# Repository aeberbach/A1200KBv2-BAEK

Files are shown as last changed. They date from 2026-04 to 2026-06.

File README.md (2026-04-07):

# A1200KBv2-BAEK</br>

What's a BAEK? It's a Big-Ass Enter Key.</br>

This is the BAEK version of the A1200KBv2 project. It is the same but for the BAEK itself and longer Left Shift key, just like the North American A2000 keyboard. These keys remove the need for two keys that are found in most A1200 keyboards, those that are blank in UK/US languages and are sometimes used for special characters in other languages.</br>
The Left Shift key is a conventionally stabilised key, same as the Right Shift. The BAEK uses the same kind of stabiliser at its base but adds another single stabiliser at the top. The key available does not provide for a vertical wire as keyboards with BAEK sometimes used - when pressing at the very top it will be slightly stiffer, but it seems to work fine.</br>
All other parts of this keyboard are substantially the same as the A1200KBv2 project.</br>

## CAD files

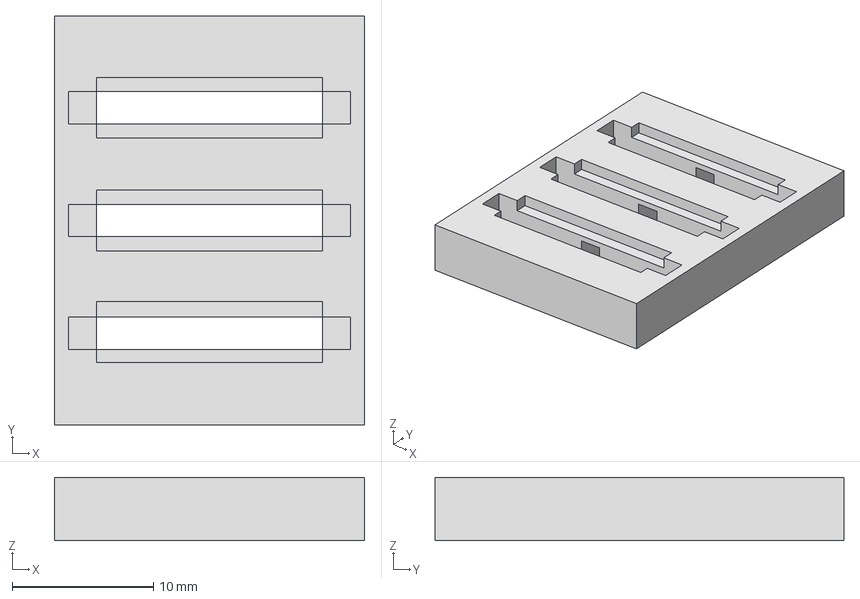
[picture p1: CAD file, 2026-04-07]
3dprint/A1200net LEDs/Lightpipe shield A1200net.stp
22.0 x 29.0 x 4.50 mm

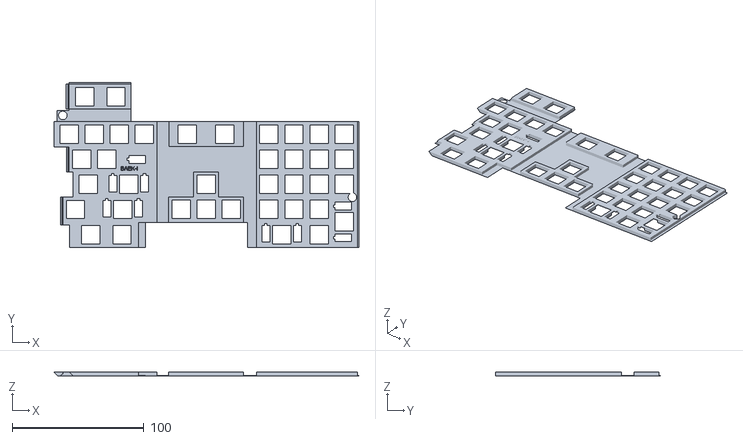
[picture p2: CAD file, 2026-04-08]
3dprint/Keyboard plates/BAEK-Right Plate.stl
231.7 x 125.0 x 3.00

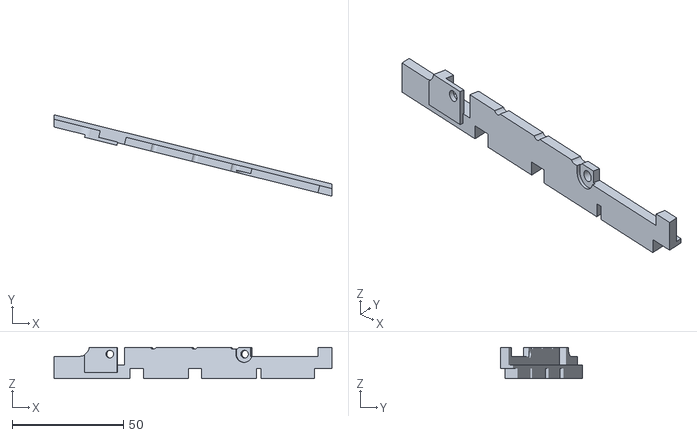
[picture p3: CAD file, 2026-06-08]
3dprint/Mounts/Universal Right Mount-Universal right mount.stl
125.2 x 36.7 x 14.0

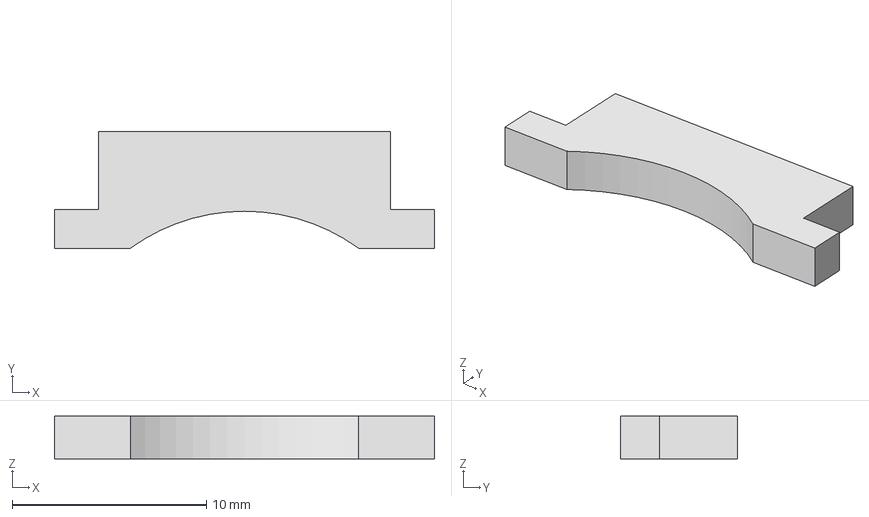
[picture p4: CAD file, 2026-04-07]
3dprint/A1200net LEDs/Light Pipe A1200net.stp
19.5 x 6.00 x 2.20 mm

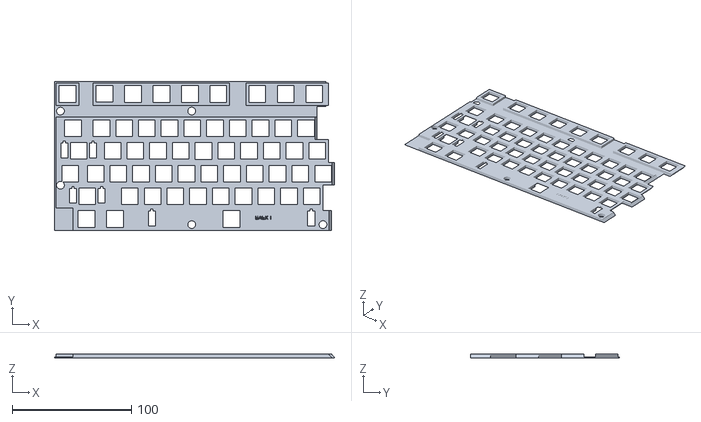
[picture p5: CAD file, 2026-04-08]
3dprint/Keyboard plates/BAEK-Left Plate.stl
234.7 x 125.0 x 3.00

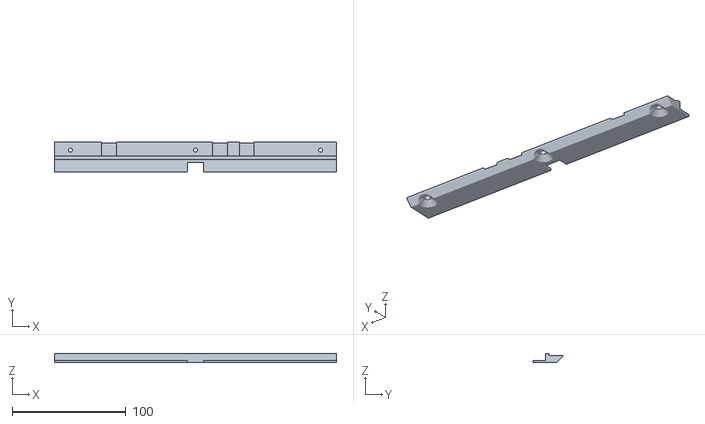
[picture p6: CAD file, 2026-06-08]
3dprint/Mounts/Lower mount.stl
248.0 x 26.0 x 7.60

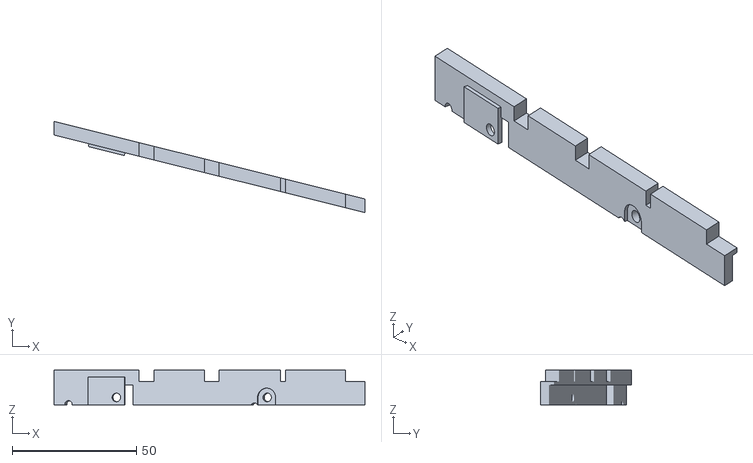
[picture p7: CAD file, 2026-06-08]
3dprint/Mounts/Universal Left Mount-Universal Left Mount.stl
125.2 x 36.7 x 14.0

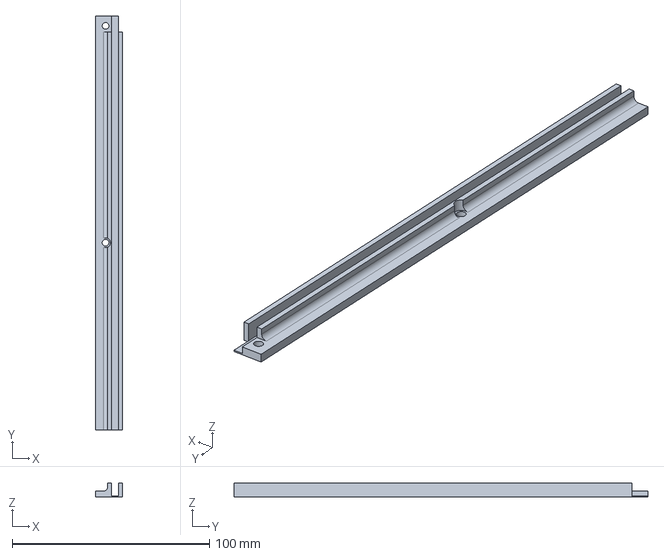
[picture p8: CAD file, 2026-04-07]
3dprint/Mounts/Back brace Right.FCStd
13.5 x 210.0 x 7.00 mm

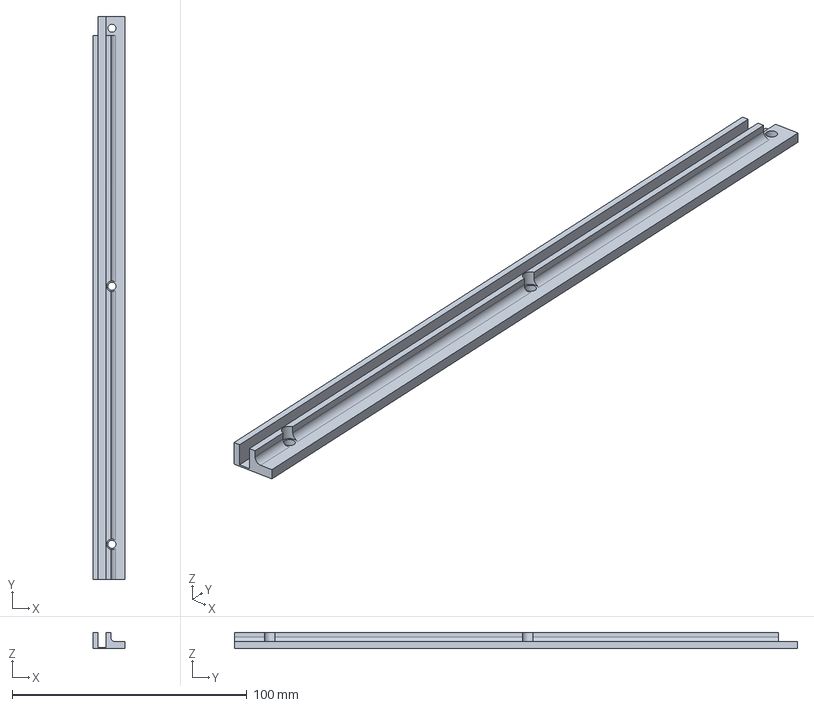
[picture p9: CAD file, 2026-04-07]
3dprint/Mounts/Back brace Left.FCStd
13.5 x 240.0 x 7.00 mm

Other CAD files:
3dprint/Commodore LEDs/Lightpipe shield Commodore.stp
3dprint/Commodore LEDs/Light Pipe Commodore.stp
3dprint/Keyboard plates/BAEK-Right Plate-I.FCStd
3dprint/Keyboard plates/BAEK-Left Plate-I.FCStd
3dprint/Mounts/Universal Left Mount.FCStd
3dprint/Mounts/Universal Right Mount.FCStd

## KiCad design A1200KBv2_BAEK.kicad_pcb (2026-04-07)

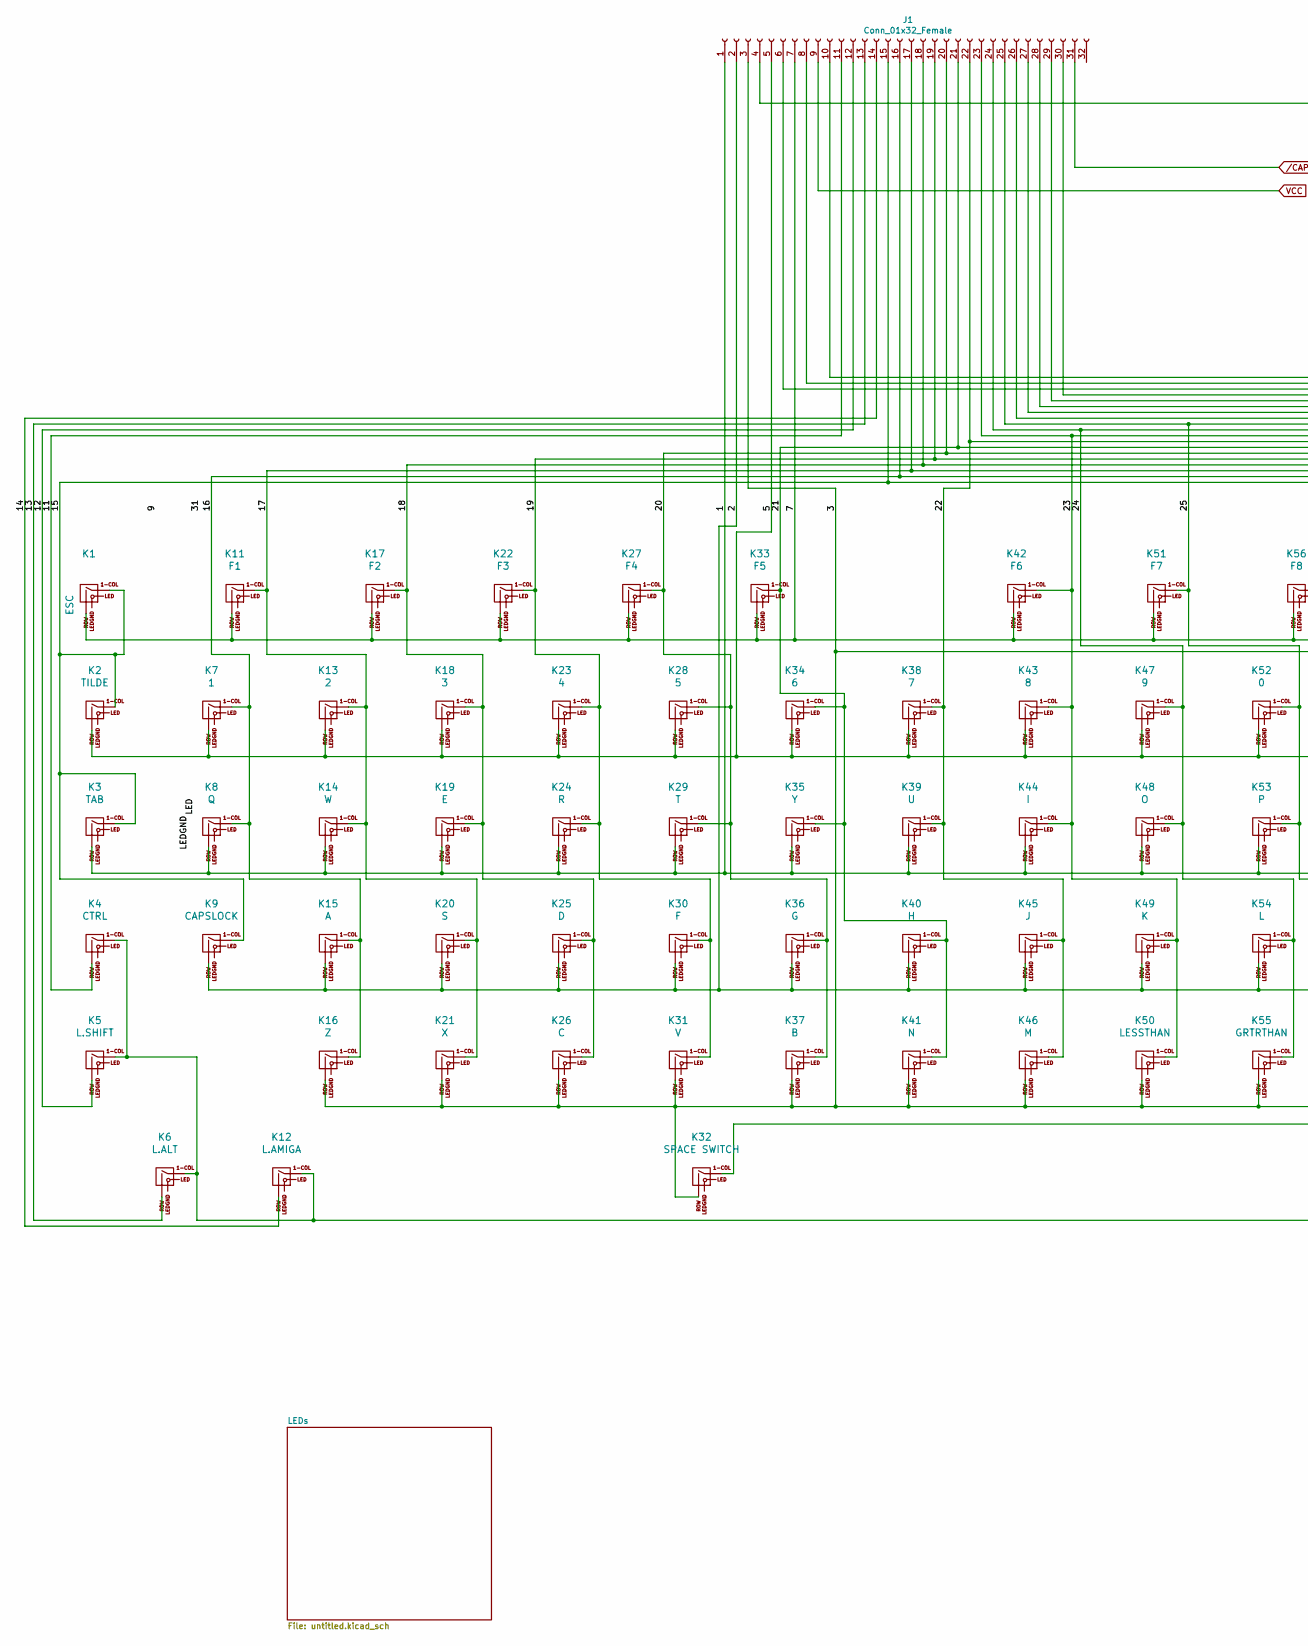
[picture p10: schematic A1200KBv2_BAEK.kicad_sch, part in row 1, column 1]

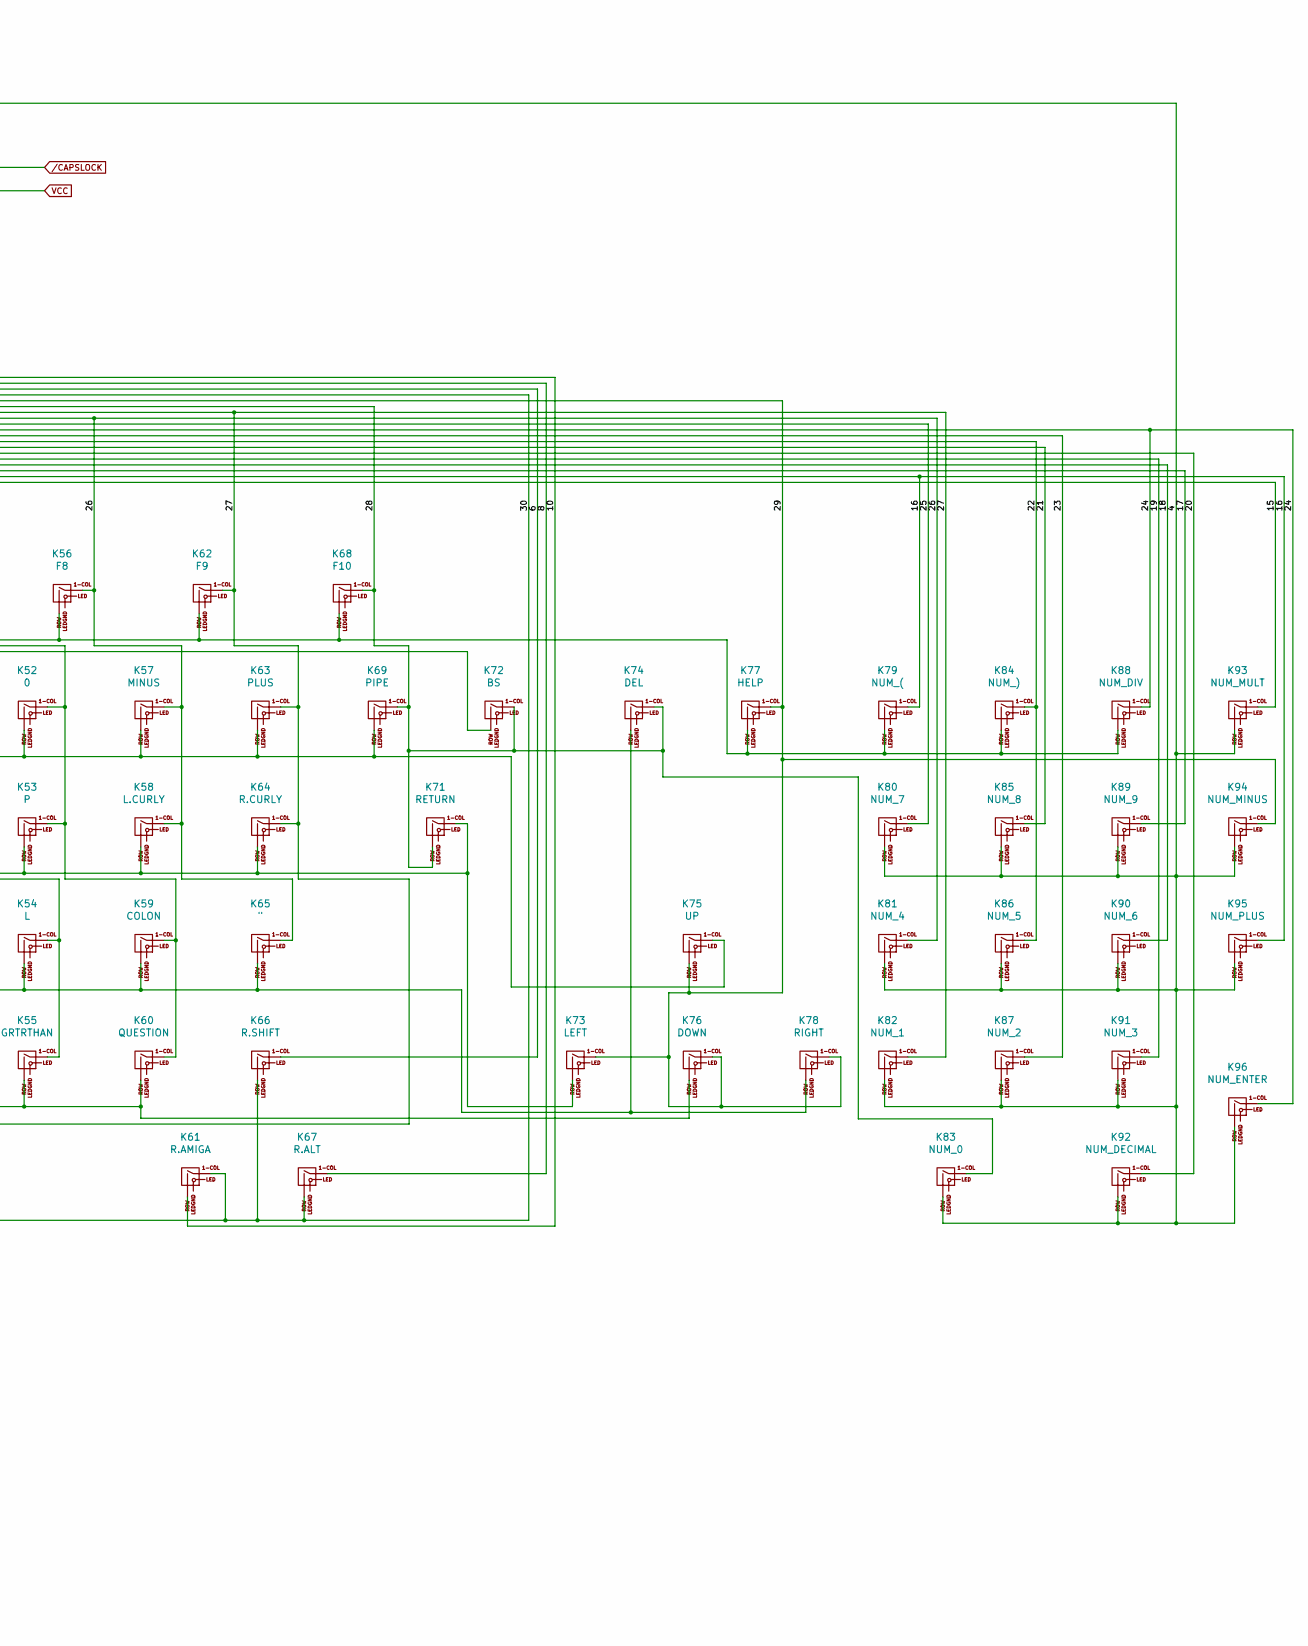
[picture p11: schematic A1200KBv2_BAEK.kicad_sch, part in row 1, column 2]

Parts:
J1: Conn_01x32_Female; FFC-1.25mm-RA-5204403245
K1: ESC; Gateron-KS33-Solderable-1U
K2: TILDE; Gateron-KS33-Solderable-1.5U
K3: TAB; KS-33-2U-stabilizer
K4: CTRL; Gateron-KS33-Solderable-1.25U
K5: L.SHIFT; KS-33-2.75U-stabilizer
K6: L.ALT; Gateron-KS33-Solderable-1.25U
K7: 1; Gateron-KS33-Solderable-1U
K8: Q; Gateron-KS33-Solderable-1U
K9: CAPSLOCK; Gateron-KS33-Solderable-1U
K11: F1; Gateron-KS33-Solderable-1.25U
K12: L.AMIGA; Gateron-KS33-Solderable-1.25U
K13: 2; Gateron-KS33-Solderable-1U
K14: W; Gateron-KS33-Solderable-1U
K15: A; Gateron-KS33-Solderable-1U
K16: Z; Gateron-KS33-Solderable-1U
K17: F2; Gateron-KS33-Solderable-1.25U
K18: 3; Gateron-KS33-Solderable-1U
K19: E; Gateron-KS33-Solderable-1U
K20: S; Gateron-KS33-Solderable-1U
K21: X; Gateron-KS33-Solderable-1U
K22: F3; Gateron-KS33-Solderable-1.25U
K23: 4; Gateron-KS33-Solderable-1U
K24: R; Gateron-KS33-Solderable-1U
K25: D; Gateron-KS33-Solderable-1U
K26: C; Gateron-KS33-Solderable-1U
K27: F4; Gateron-KS33-Solderable-1.25U
K28: 5; Gateron-KS33-Solderable-1U
K29: T; Gateron-KS33-Solderable-1U
K30: F; Gateron-KS33-Solderable-1U
K31: V; Gateron-KS33-Solderable-1U
K32: SPACE SWITCH; KS-33-8U-space
K33: F5; Gateron-KS33-Solderable-1.25U
K34: 6; Gateron-KS33-Solderable-1U
K35: Y; Gateron-KS33-Solderable-1U
K36: G; Gateron-KS33-Solderable-1U
K37: B; Gateron-KS33-Solderable-1U
K38: 7; Gateron-KS33-Solderable-1U
K39: U; Gateron-KS33-Solderable-1U
K40: H; Gateron-KS33-Solderable-1U
K41: N; Gateron-KS33-Solderable-1U
K42: F6; Gateron-KS33-Solderable-1.25U
K43: 8; Gateron-KS33-Solderable-1U
K44: I; Gateron-KS33-Solderable-1U
K45: J; Gateron-KS33-Solderable-1U
K46: M; Gateron-KS33-Solderable-1U
K47: 9; Gateron-KS33-Solderable-1U
K48: O; Gateron-KS33-Solderable-1U
K49: K; Gateron-KS33-Solderable-1U
K50: LESSTHAN; Gateron-KS33-Solderable-1U
K51: F7; Gateron-KS33-Solderable-1.25U
K52: 0; Gateron-KS33-Solderable-1U
K53: P; Gateron-KS33-Solderable-1U
K54: L; Gateron-KS33-Solderable-1U
K55: GRTRTHAN; Gateron-KS33-Solderable-1U
K56: F8; Gateron-KS33-Solderable-1.25U
K57: MINUS; Gateron-KS33-Solderable-1U
K58: L.CURLY; Gateron-KS33-Solderable-1U
K59: COLON; Gateron-KS33-Solderable-1U
K60: QUESTION; Gateron-KS33-Solderable-1U
K61: R.AMIGA; Gateron-KS33-Solderable-1.25U
K62: F9; Gateron-KS33-Solderable-1.25U
K63: PLUS; Gateron-KS33-Solderable-1U
K64: R.CURLY; Gateron-KS33-Solderable-1U
K65: "; Gateron-KS33-Solderable-1U
K66: R.SHIFT; KS-33-2U-stabilizer
K67: R.ALT; Gateron-KS33-Solderable-1.25U
K68: F10; Gateron-KS33-Solderable-1.25U
K69: PIPE; Gateron-KS33-Solderable-1U
K71: RETURN; KS-33-ANSI-BAEK-stabilizer
K72: BS; Gateron-KS33-Solderable-1U
K73: LEFT; Gateron-KS33-Solderable-1U
K74: DEL; Gateron-KS33-Solderable-1.5U
K75: UP; Gateron-KS33-Solderable-1U
K76: DOWN; Gateron-KS33-Solderable-1U
K77: HELP; Gateron-KS33-Solderable-1.5U
K78: RIGHT; Gateron-KS33-Solderable-1U
K79: NUM_(; Gateron-KS33-Solderable-1U
K80: NUM_7; Gateron-KS33-Solderable-1U
K81: NUM_4; Gateron-KS33-Solderable-1U
K82: NUM_1; Gateron-KS33-Solderable-1U
K83: NUM_0; KS-33-2U-stabilizer
K84: NUM_); Gateron-KS33-Solderable-1U
K85: NUM_8; Gateron-KS33-Solderable-1U
K86: NUM_5; Gateron-KS33-Solderable-1U
K87: NUM_2; Gateron-KS33-Solderable-1U
K88: NUM_DIV; Gateron-KS33-Solderable-1U
K89: NUM_9; Gateron-KS33-Solderable-1U
K90: NUM_6; Gateron-KS33-Solderable-1U
K91: NUM_3; Gateron-KS33-Solderable-1U
K92: NUM_DECIMAL; Gateron-KS33-Solderable-1U
K93: NUM_MULT; Gateron-KS33-Solderable-1U
K94: NUM_MINUS; Gateron-KS33-Solderable-1U
K95: NUM_PLUS; Gateron-KS33-Solderable-1U
K96: NUM_ENTER; KS-33-2U-stabilizer

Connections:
/1: J1.1, K3.2 (ROW), K8.2 (ROW), K14.2 (ROW), K19.2 (ROW), K24.2 (ROW), K29.2 (ROW), K35.2 (ROW), K39.2 (ROW), K44.2 (ROW), K48.2 (ROW), K53.2 (ROW), K58.2 (ROW), K64.2 (ROW), K71.1 (COL), K73.2 (ROW)
/2: J1.2, K9.2 (ROW), K15.2 (ROW), K20.2 (ROW), K25.2 (ROW), K30.2 (ROW), K36.2 (ROW), K40.2 (ROW), K45.2 (ROW), K49.2 (ROW), K54.2 (ROW), K59.2 (ROW), K65.2 (ROW), K74.2 (ROW), K78.2 (ROW)
/3: J1.3, K16.2 (ROW), K21.2 (ROW), K26.2 (ROW), K31.2 (ROW), K32.2 (ROW), K37.2 (ROW), K41.2 (ROW), K46.2 (ROW), K50.2 (ROW), K55.2 (ROW), K60.2 (ROW), K72.2 (ROW), K76.2 (ROW)
/4: J1.4, K80.2 (ROW), K81.2 (ROW), K82.2 (ROW), K83.2 (ROW), K85.2 (ROW), K86.2 (ROW), K87.2 (ROW), K89.2 (ROW), K90.2 (ROW), K91.2 (ROW), K92.2 (ROW), K93.2 (ROW), K94.2 (ROW), K95.2 (ROW), K96.2 (ROW)
/5: J1.5, K2.2 (ROW), K7.2 (ROW), K13.2 (ROW), K18.2 (ROW), K23.2 (ROW), K28.2 (ROW), K34.2 (ROW), K38.2 (ROW), K43.2 (ROW), K47.2 (ROW), K52.2 (ROW), K57.2 (ROW), K63.2 (ROW), K69.2 (ROW), K75.1 (COL)
/6: J1.6, K66.1 (COL)
/7: J1.7, K1.2 (ROW), K11.2 (ROW), K17.2 (ROW), K22.2 (ROW), K27.2 (ROW), K33.2 (ROW), K42.2 (ROW), K51.2 (ROW), K56.2 (ROW), K62.2 (ROW), K68.2 (ROW), K77.2 (ROW), K79.2 (ROW), K84.2 (ROW), K88.2 (ROW)
/8: J1.8, K67.1 (COL)
/10: J1.10, K61.2 (ROW)
/11: J1.11, K4.2 (ROW)
/12: J1.12, K5.2 (ROW)
/13: J1.13, K6.2 (ROW)
/14: J1.14, K12.2 (ROW)
/15: J1.15, K1.1 (COL), K2.1 (COL), K3.1 (COL), K9.1 (COL), K93.1 (COL)
/16: J1.16, K7.1 (COL), K8.1 (COL), K15.1 (COL), K16.1 (COL), K79.1 (COL), K95.1 (COL)
/17: J1.17, K11.1 (COL), K13.1 (COL), K14.1 (COL), K20.1 (COL), K21.1 (COL), K89.1 (COL)
/18: J1.18, K17.1 (COL), K18.1 (COL), K19.1 (COL), K25.1 (COL), K26.1 (COL), K90.1 (COL)
/19: J1.19, K22.1 (COL), K23.1 (COL), K24.1 (COL), K30.1 (COL), K31.1 (COL), K91.1 (COL)
/20: J1.20, K27.1 (COL), K28.1 (COL), K29.1 (COL), K36.1 (COL), K37.1 (COL), K92.1 (COL)
/21: J1.21, K33.1 (COL), K34.1 (COL), K35.1 (COL), K40.1 (COL), K41.1 (COL), K85.1 (COL)
/22: J1.22, K38.1 (COL), K39.1 (COL), K45.1 (COL), K46.1 (COL), K84.1 (COL), K86.1 (COL)
/23: J1.23, K42.1 (COL), K43.1 (COL), K44.1 (COL), K49.1 (COL), K50.1 (COL), K87.1 (COL)
/24: J1.24, K47.1 (COL), K48.1 (COL), K54.1 (COL), K55.1 (COL), K88.1 (COL), K96.1 (COL)
/25: J1.25, K51.1 (COL), K52.1 (COL), K53.1 (COL), K59.1 (COL), K60.1 (COL), K80.1 (COL)
/26: J1.26, K56.1 (COL), K57.1 (COL), K58.1 (COL), K65.1 (COL), K81.1 (COL)
/27: J1.27, K32.1 (COL), K62.1 (COL), K63.1 (COL), K64.1 (COL), K82.1 (COL)
/28: J1.28, K68.1 (COL), K69.1 (COL), K71.2 (ROW), K72.1 (COL), K74.1 (COL), K83.1 (COL)
/29: J1.29, K73.1 (COL), K75.2 (ROW), K76.1 (COL), K77.1 (COL), K78.1 (COL), K94.1 (COL)
/30: J1.30, K4.1 (COL), K5.1 (COL), K6.1 (COL), K12.1 (COL), K61.1 (COL), K66.2 (ROW), K67.2 (ROW)
VCC: J1.9; also elsewhere on the board
/CAPSLOCK: J1.31; also elsewhere on the board

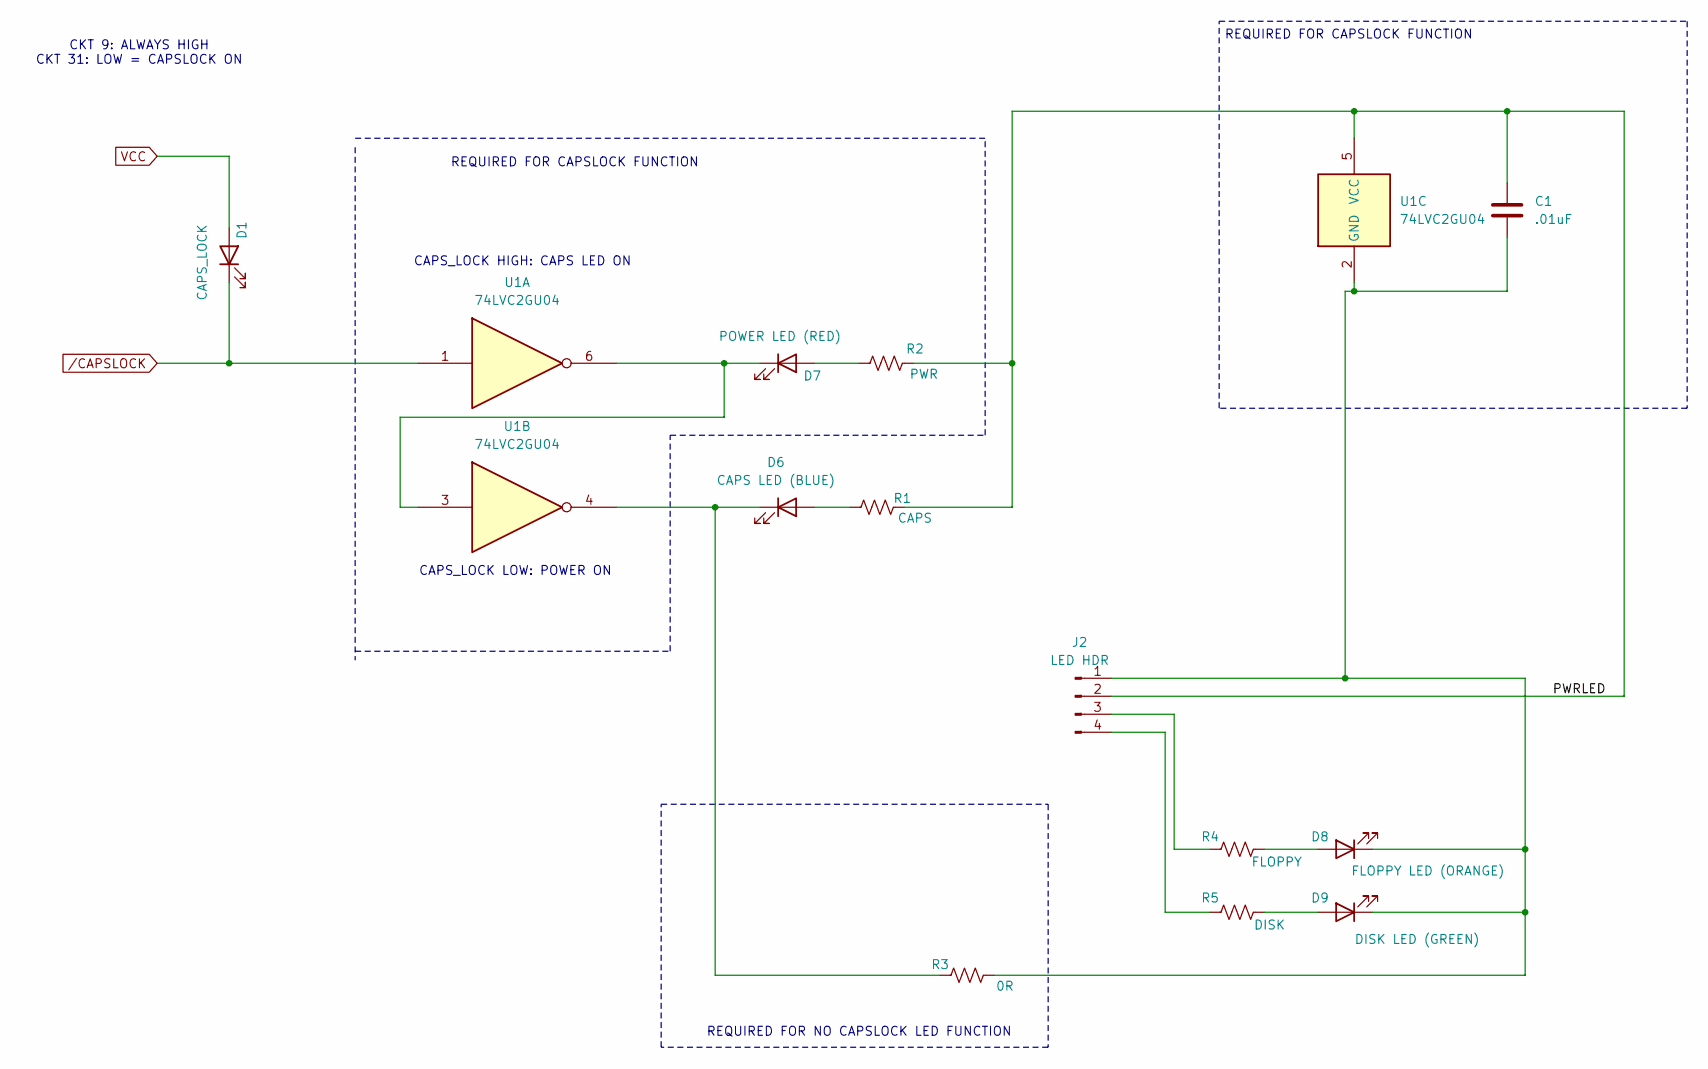
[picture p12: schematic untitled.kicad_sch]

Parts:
C1: .01uF; C_0805_2012Metric_Pad1.18x1.45mm_HandSolder
D1: CAPS_LOCK; LED_0805_2012Metric
D6: CAPS LED (BLUE); LED_0805_2012Metric
D7: POWER LED (RED); LED_0805_2012Metric
D8: FLOPPY LED (ORANGE); LED_0805_2012Metric
D9: DISK LED (GREEN); LED_0805_2012Metric
J2: LED HDR; PinHeader_1x04_P2.54mm_Vertical
R1: CAPS; R_0805_2012Metric_Pad1.20x1.40mm_HandSolder
R2: PWR; R_0805_2012Metric_Pad1.20x1.40mm_HandSolder
R3: 0R; R_0805_2012Metric_Pad1.20x1.40mm_HandSolder
R4: FLOPPY; R_0805_2012Metric_Pad1.20x1.40mm_HandSolder
R5: DISK; R_0805_2012Metric_Pad1.20x1.40mm_HandSolder
U1: 74LVC2GU04; SOT-23-6

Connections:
/LEDs/PWRLED: C1.1, J2.2, R1.2, R2.2, U1.5 (VCC)
unnamed: D6.2 (A), R1.1
unnamed: D6.1 (K), R3.1, U1.4
unnamed: D7.2 (A), R2.1
unnamed: D7.1 (K), U1.3, U1.6
unnamed: D8.2 (A), R4.2
unnamed: C1.2, D8.1 (K), D9.1 (K), J2.1, R3.2, U1.2 (GND)
unnamed: D9.2 (A), R5.2
unnamed: J2.3, R4.1
unnamed: J2.4, R5.1
VCC: D1.2 (A); also elsewhere on the board
/CAPSLOCK: D1.1 (K), U1.1; also elsewhere on the board

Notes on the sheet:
CAPS_LOCK LOW: POWER ON
CKT 9: ALWAYS HIGH CKT 31: LOW = CAPSLOCK ON
REQUIRED FOR CAPSLOCK FUNCTION
CAPS_LOCK HIGH: CAPS LED ON
REQUIRED FOR NO CAPSLOCK LED FUNCTION

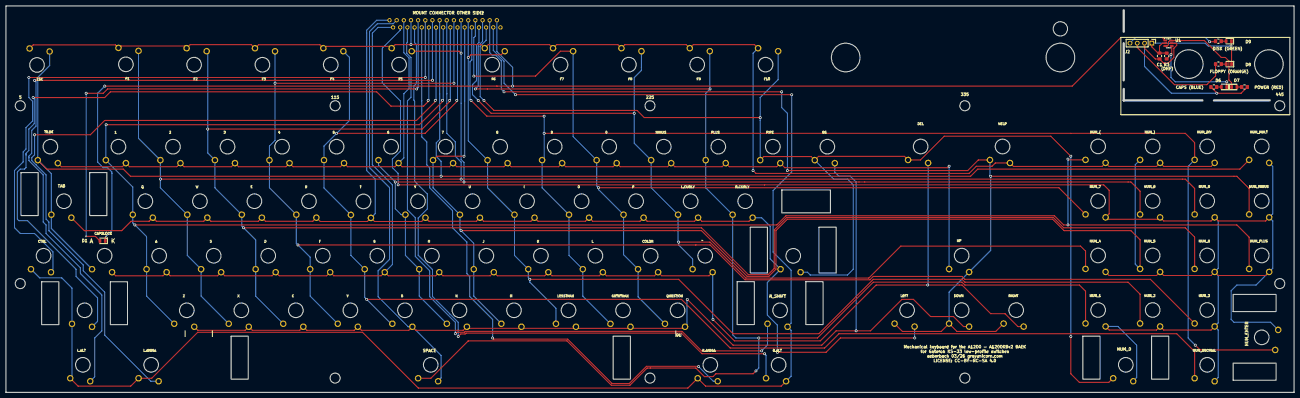
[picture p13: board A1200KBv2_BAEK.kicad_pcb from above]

Board: 2 copper layers, 450.0 x 135.0 mm, 108 parts (1 on the bottom side), 41 nets.

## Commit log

2026-04-07 Commit of BAEK project
    [A1200KBv2-B_Cu.gbr, A1200KBv2-B_Mask.gbr, A1200KBv2-Edge_Cuts.gbr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]
2026-04-08 STLs for keyboard plates
    [BAEK-Left Plate.stl, BAEK-Right Plate.stl]
2026-04-08 Organise 3D print files
    [Light Pipe A1200net.stp, Light Pipe Commodore.stp, Lightpipe shield A1200net.stp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]
2026-06-08 Revised mounts
    [Lower mount.stl, Universal Left Mount-Universal Left Mount.stl, Universal Right Mount-Universal right mount.stl]

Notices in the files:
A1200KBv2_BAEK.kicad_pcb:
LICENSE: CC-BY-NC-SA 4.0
